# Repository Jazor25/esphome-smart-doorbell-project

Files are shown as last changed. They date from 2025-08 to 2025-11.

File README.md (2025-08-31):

# ESPHome Smart Doorbell Project

This smart doorbell project transforms a traditional doorbell into an intelligent system using ESPHome and Home Assistant integration. The system detects doorbell button presses and activates a relay-controlled chime while providing remote control capabilities. 

Doorbell detections can be used for home assistant automations such as taking a photo with your existing security camera on-press and send it with a notification to your mobile devices. You can also deactivate the gong/chime at times where you need silence.

Some ideas come from the excellent work of [Marcel Zuidwijk](https://www.zuidwijk.com/esphome-based-doorbell/).

### Visuals
More images are in the img folder.

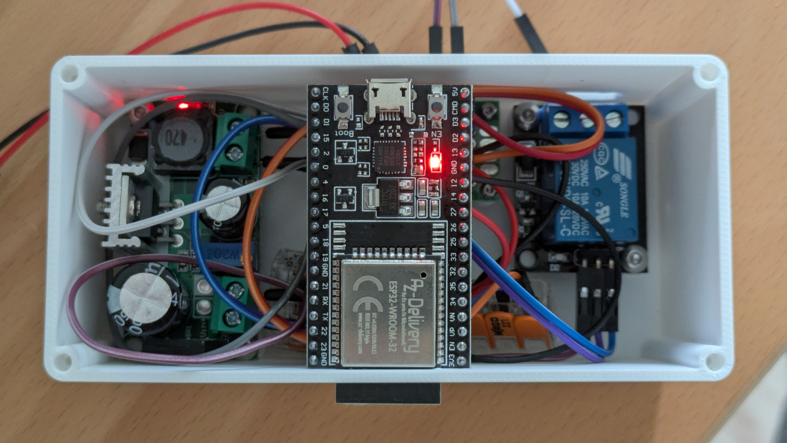
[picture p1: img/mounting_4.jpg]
Mounting

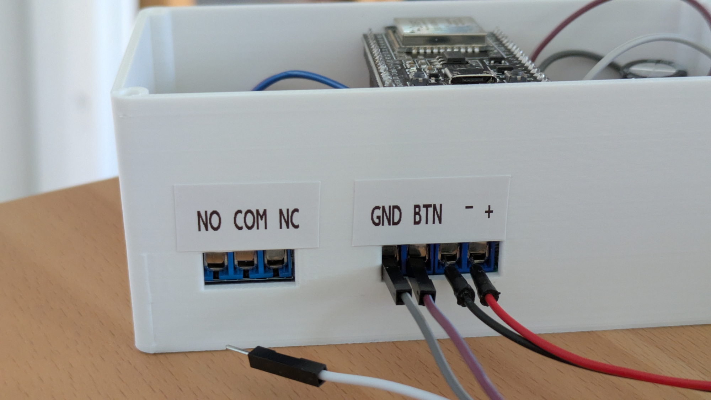
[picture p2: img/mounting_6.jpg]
Connections

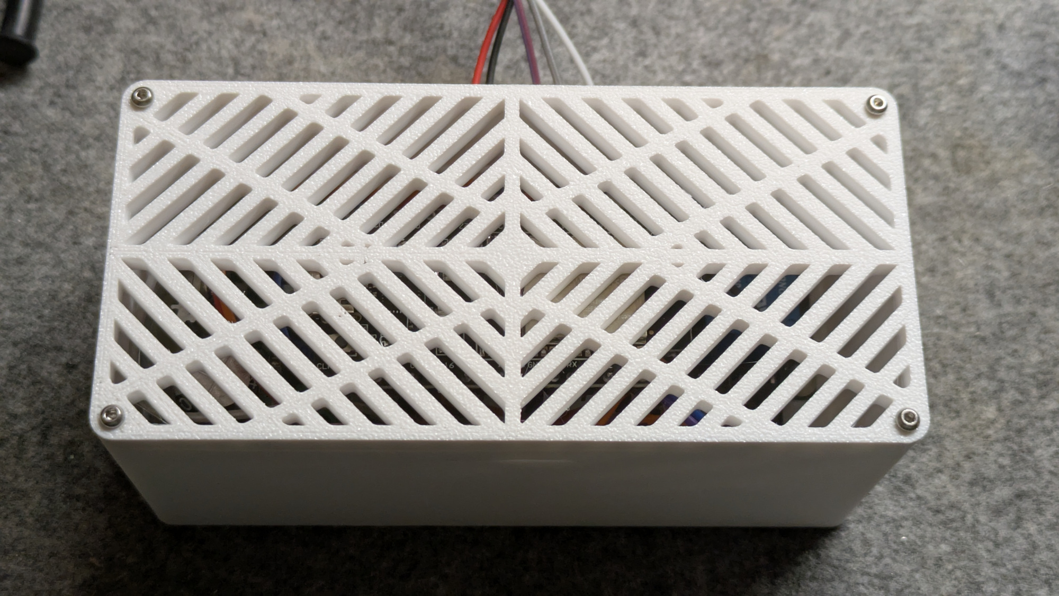
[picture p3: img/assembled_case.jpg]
Assembled

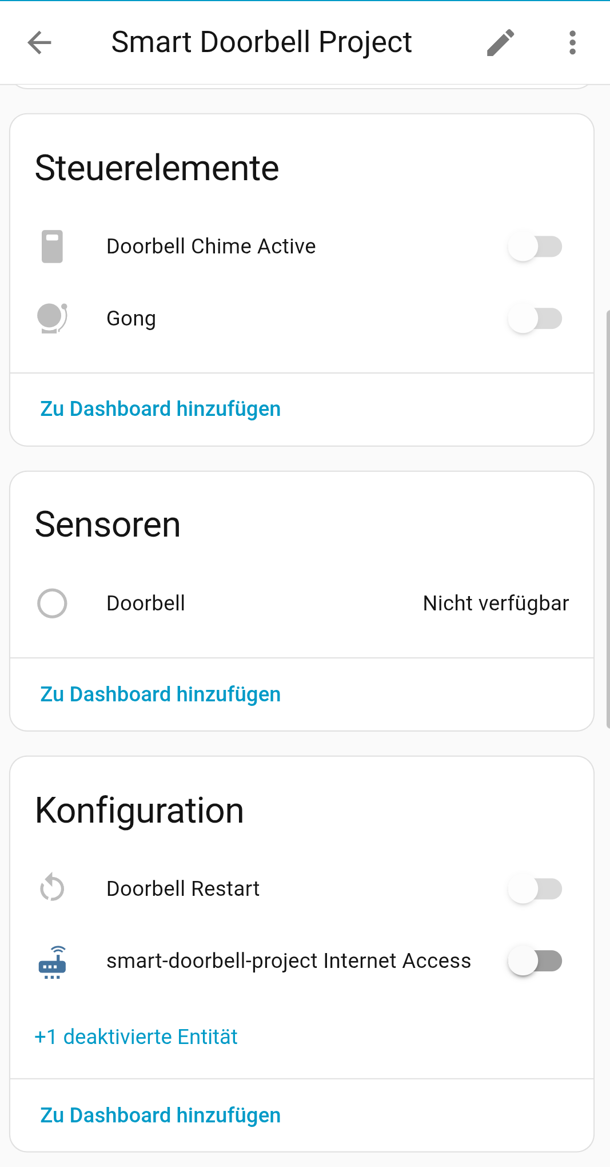
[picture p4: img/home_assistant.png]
In Home Assistant

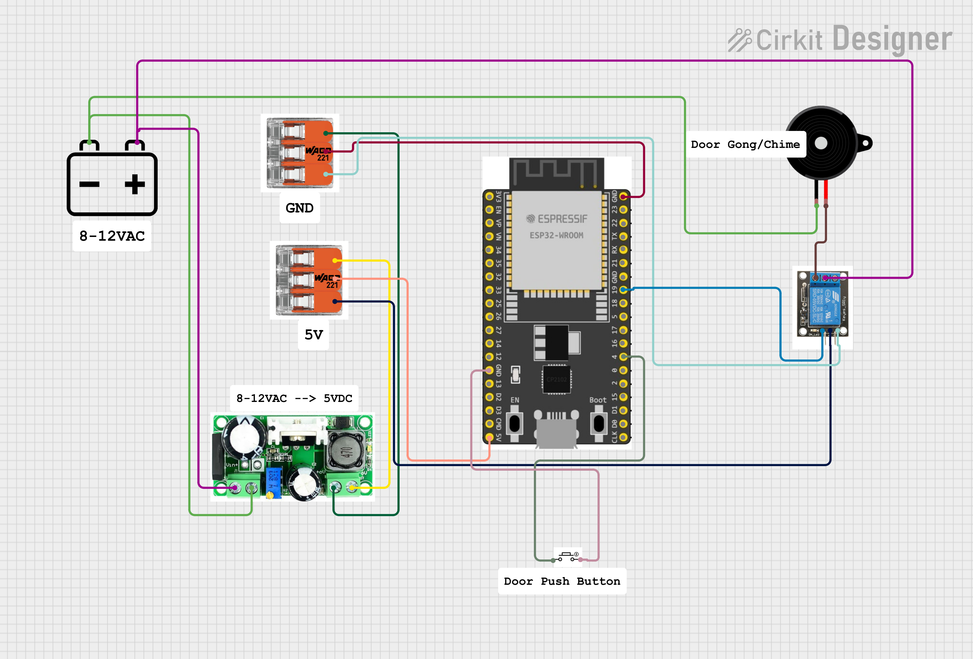
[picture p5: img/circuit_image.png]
Circuit Design


### Features
- Detects button presses via GPIO input with debouncing to avoid false positives
- Enable/disable chime remotely via Home Assistant in case you need silence
- Connects to home network with fallback hotspot
- Home Assistant Integration 
- Uptime and WiFi signal strength monitoring
- Restart device remotely
- Manual gong trigger via Home Assistant to annoy your housemate ;)

## Required Hardware
* ESP32 Development Board (Used: ESP32 V4 with CP2102, AZDelivery). As most dev boards, this one can handle 5VDC.
* 1× AC/DC LM2596hv Step-Down Voltage Regulator (to convert AC to DC and decrease voltage to 5V to power ESP32 and Relais module). AC to DC is important in case you want to connect this project to your existing doorbell transformer which typically runs on 8-12VAC 
* 1× SRD-05VDC-5L-C Relais Module because the typical Gong needs more amp that an esp32 can deliver. This Relais can also handle AC which would be tricky using Mosfets.
* To be powered over doorbell transformer (usually 8-12VAC) or external power source. Alternatively a separate transformer can be used. A separate transformer that delivers 5VDC would make the above mentioned step-down regulator dispensable.
* wiring cables
* Optional: WAGO connectors, terminal clamps and perfboard for easier wiring (see images)

## Wiring & Setup

## Installation & Configuration
See [docs/installation_configuration.md](docs/installation_configuration.md)  

### GPIO Pin Assignments
- **GPIO4**: Doorbell button input (with internal pullup)
- **GPIO19**: Relay control output (to trigger the gong)

### Power Supply Setup
1. **Input**: 8-12VAC from doorbell transformer
2. **Conversion**: LM2596hv Step-Down Voltage Regulator converts AC to 5VDC
3. **Distribution**: 5VDC powers both ESP32 and relay module

### Connection Diagram
```
Doorbell Transformer (8-12VAC)
    ↓
LM2596hv Voltage Regulator
    ↓ (5VDC)
    ├── ESP32 Board (VCC + GND)
    └── SRD-05VDC-5L-C Relay Module (VCC + GND)

Doorbell Button → GPIO4 (ESP32)
ESP32 GPIO19 → Relay Control Input
Relay Output → gong
```

### Assembly Notes
- Ensure proper AC/DC isolation when working with doorbell transformer
- Test all connections before final installation
- Voltage Regulation: The buck converter must be precisely adjusted to 5V to prevent damage to the ESP32 and connected modules. Connect 8-12VAC to the input pins, attach a multimeter (set to voltage mode) to the output pins, and carefully adjust the potentiometer with a screwdriver until the multimeter reads exactly 5VDC. This may be readjusted when you switch to different input voltage.

### 3D Print Case Hardware
- 4x Ruthex M3 Threaded Inserts
- 4x M3 Screws
- 6x Ruthex M2 Threaded Inserts
- 6x M2 Screws

### Key Configuration Options

**Doorbell Input**:
- Pin: GPIO4 with internal pullup
- Debouncing: 25ms delays to prevent false triggers

**Relay Output**:
- Pin: GPIO19
- Activation time: 1 second pulse to trigger the gong
- Control: global chime (gong) enable/disable setting

**Network**:
- Primary: Your WiFi network
- Fallback: Creates "Smart-Doorbell-Project" hotspot
- Captive portal for easy configuration
- Basic functionality runs without any network connection, to ensure that the doorbell works proberly in case of network outage

### Customization Options
- Change GPIO pins by modifying pin numbers in YAML
- Adjust chime duration by changing delay value
- Modify debounce timing for different button types
- Add additional sensors or switches as needed

### Operation Modes

**Enabled (Default)**:
- Doorbell button press → Relay activates → Chime sounds
- Green indicator in Home Assistant

**Disabled**:
- Doorbell button press → No relay activation → Silent
- Red indicator in Home Assistant
- Button press still logged for notifications

## Troubleshooting

### WiFi Connection Issues

**Device won't connect to WiFi**:
1. Verify `secrets.yaml` contains correct WiFi credentials
2. Check WiFi signal strength at installation location
3. Ensure WiFi network is 2.4GHz (ESP32 doesn't support 5GHz)
4. Look for fallback hotspot "Smart-Doorbell-Project"

**Fallback Hotspot Setup**:
1. Connect to "Smart-Doorbell-Project" network
2. Use password from `ap_wifi_password_sdb` in secrets
3. Navigate to captive portal page
4. Configure WiFi settings

### Hardware Issues

**Doorbell not responding**:
1. Check GPIO4 wiring and connections
2. Verify button is normally open (closes when pressed)
3. Test button with multimeter (should show continuity when pressed)
4. Check ESPHome logs for button state changes

**Relay not activating**:
1. Verify GPIO19 connection to relay module
2. Check 5V power supply to relay module
3. Test relay manually with multimeter
4. Ensure "Doorbell Chime Active" switch is ON in Home Assistant

## License
This project is published under [CC BY-NC-SA 4.0](https://creativecommons.org/licenses/by-nc-sa/4.0/).

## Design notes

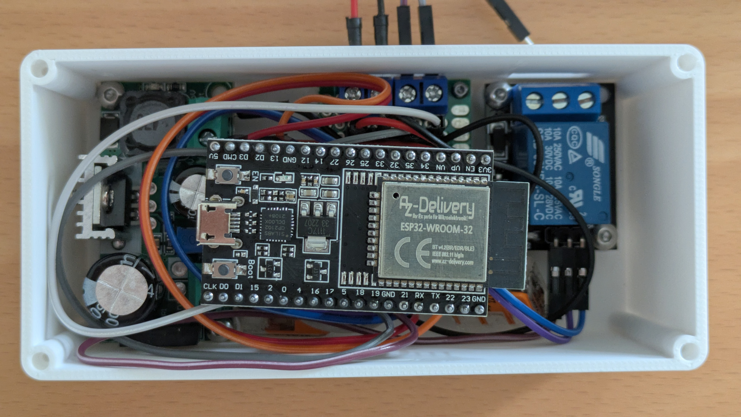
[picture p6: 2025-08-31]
img/mounting_7.jpg

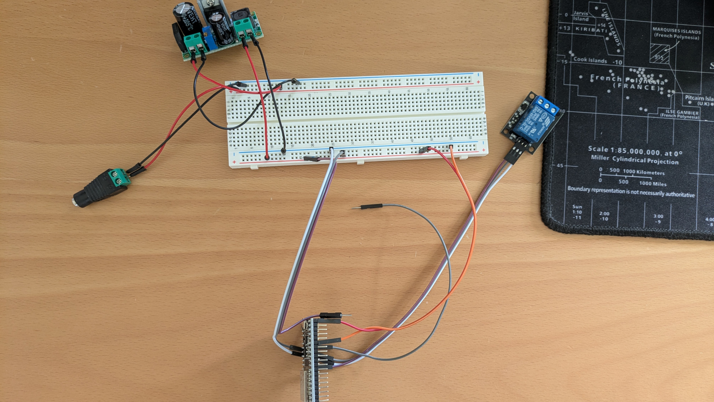
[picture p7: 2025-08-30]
img/prototype.jpg

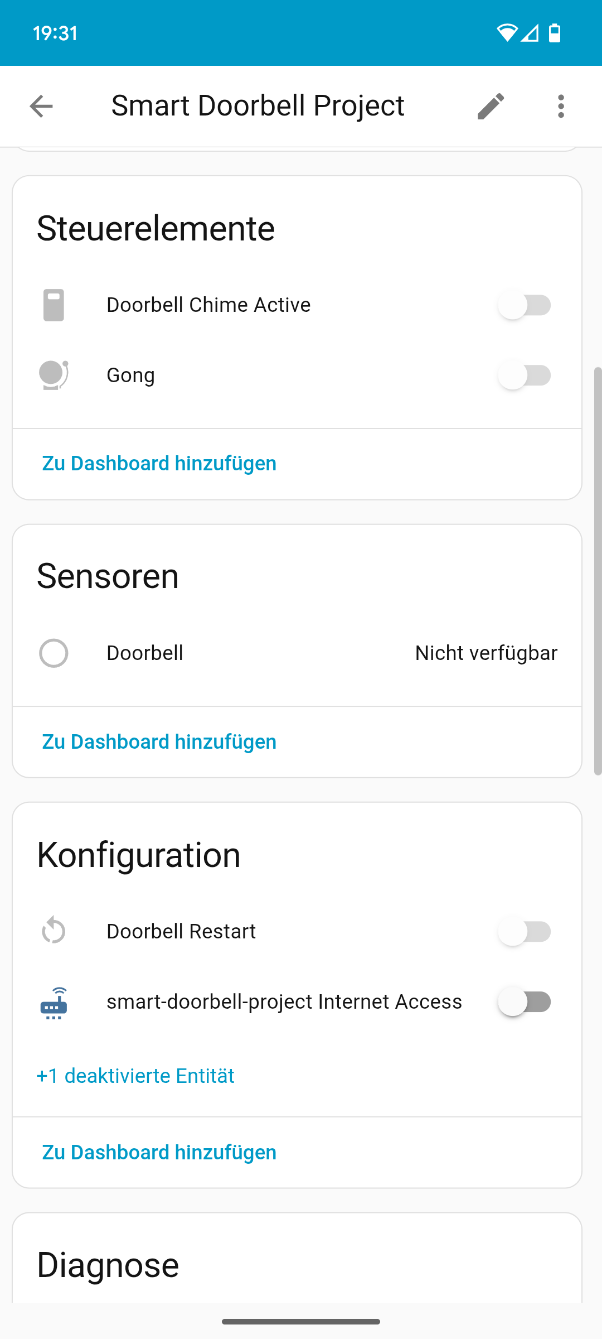
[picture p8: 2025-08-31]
img/Screenshot_20250831-193113.png

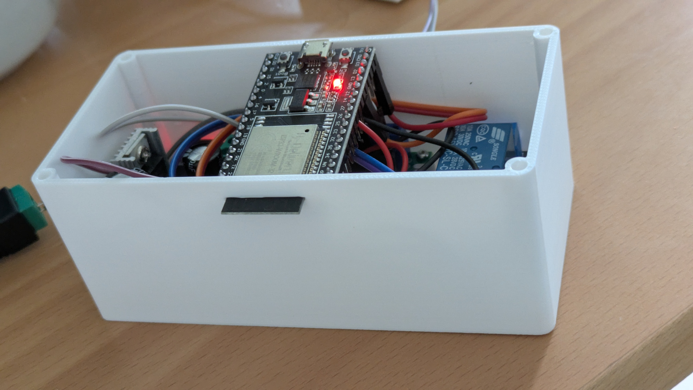
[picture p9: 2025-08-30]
img/mounting_5.jpg

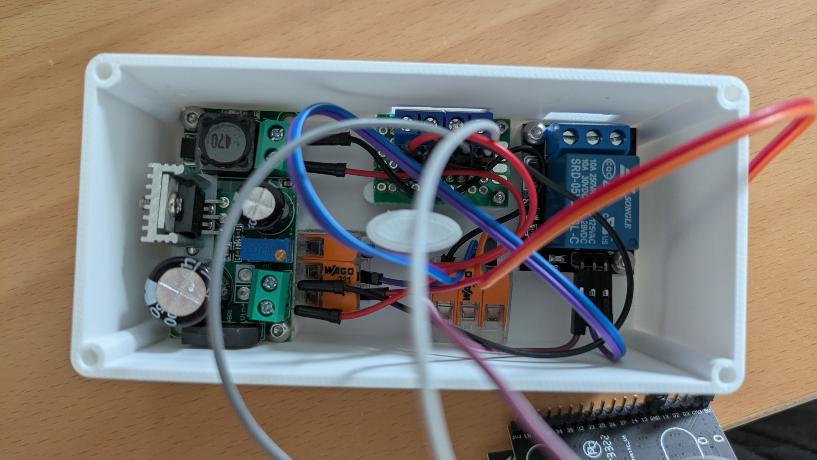
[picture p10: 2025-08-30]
img/mounting_3.jpg

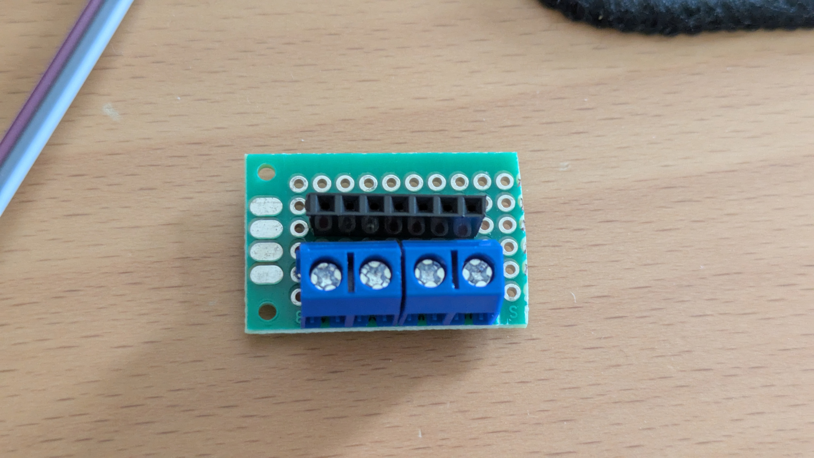
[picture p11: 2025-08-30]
img/terminal_clamps.jpg

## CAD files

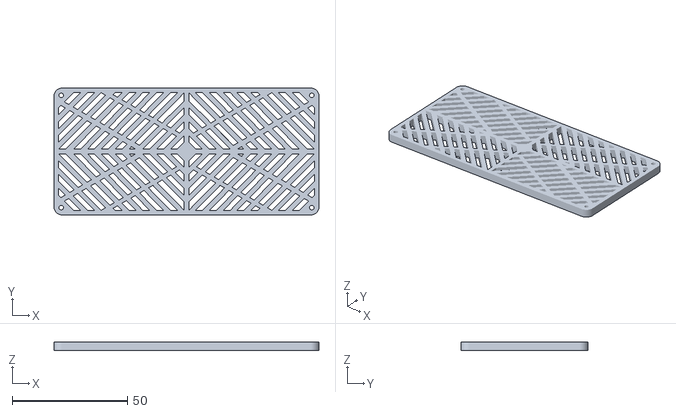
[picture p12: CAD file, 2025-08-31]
3d-print-files/Case_Top.stl
115.0 x 55.0 x 4.50

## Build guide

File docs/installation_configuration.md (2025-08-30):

# Adding ESPHome Smart Doorbell Project to Home Assistant

## Method 1: ESPHome Add-on (Recommended)

### Prerequisites
- Home Assistant with Supervisor (Home Assistant OS or Supervised)
- ESPHome Add-on installed

### Step-by-Step Instructions

#### 1. Install ESPHome Add-on
1. Go to **Settings** → **Add-ons** → **Add-on Store**
2. Search for "ESPHome" 
3. Click **Install** on the official ESPHome add-on
4. Start the add-on and enable **Start on boot**

#### 2. Add Your Device
1. Open ESPHome add-on web UI
2. Click **+ NEW DEVICE**
3. Choose **Continue** 
4. Enter device details:
   - **Name**: `smart-doorbell-project`
   - **Device Type**: Choose ESP32
5. Skip the wireless credentials (we'll use existing config)

#### 3. Upload Your Configuration
1. In ESPHome dashboard, click **EDIT** on your new device
2. Replace the generated content with your `smart-doorbell-project.yaml` content
3. Create a `secrets.yaml` file with:
   ```yaml
   wifi_ssid: "Your_WiFi_Name"
   wifi_password: "Your_WiFi_Password"
   api_encryption_key_sdb: "your-32-character-base64-encryption-key"
   ota_password_sdb: "your-secure-ota-password"
   ap_wifi_password_sdb: "your-hotspot-password"
   ```
4. Click **SAVE**

#### 4. Compile and Flash
1. Click **INSTALL** 
2. Choose **Wirelessly** (if device is already flashed) or **Plug into this computer**
3. Wait for compilation and upload

#### 5. Auto-Discovery in Home Assistant
- Once online, the device should appear in **Settings** → **Devices & Services**
- Look for "ESPHome" integration with your device
- Click **CONFIGURE** if prompted

## Method 2: Standalone ESPHome Installation

### If you're running ESPHome separately (not as HA add-on):

#### 1. Ensure API Configuration
Your configuration already has the API enabled:
```yaml
api:
  encryption:
    key: !secret api_encryption_key_sdb
```

#### 2. Manual Integration
1. Go to **Settings** → **Devices & Services**
2. Click **+ ADD INTEGRATION**
3. Search for "ESPHome"
4. Enter your ESP32's IP address
5. Enter the encryption key from your ESPHome config

## Method 3: MQTT Integration (Alternative)

### If you prefer MQTT, add this to your ESPHome config:

```yaml
mqtt:
  broker: your_mqtt_broker_ip
  username: !secret mqtt_username
  password: !secret mqtt_password
  discovery: true
  discovery_retain: false
  topic_prefix: esphome/smart_doorbell_project
```

## Device Configuration for Better HA Integration

### Add Device Information
Add this to your ESPHome configuration for better device identification:

```yaml
esphome:
  name: smart-doorbell-project
  friendly_name: Smart Doorbell Project
  comment: "Smart doorbell with chime control system"
  project:
    name: "custom.smart_doorbell"
    version: "1.0"

# Device information for Home Assistant
device_info:
  manufacturer: "Custom Build"
  model: "ESP32 Smart Doorbell"
  sw_version: "1.0"
```

## Expected Home Assistant Entities

After successful integration, you'll see these entities:

### 🔔 **Doorbell Controls**
- `switch.doorbell_chime_active` - Enable/disable the chime
- `switch.doorbell_restart` - Remotely restart the device

### � **Sensors**
- `binary_sensor.doorbell` - Shows when doorbell button is pressed
- `sensor.doorbell_uptime` - Device uptime
- `sensor.doorbell_wifi_signal` - WiFi signal strength

### 🏠 **Device Status**
- `binary_sensor.smart_doorbell_project_status` (online/offline)

## Creating a Dashboard Card

### Example Lovelace Card Configuration:

```yaml
type: entities
title: Smart Doorbell System
entities:
  - entity: binary_sensor.doorbell
    name: Doorbell Button
  - entity: switch.doorbell_chime_active
    name: Chime Active
  - type: divider
  - entity: sensor.doorbell_uptime
    name: System Uptime
  - entity: sensor.doorbell_wifi_signal
    name: WiFi Signal
  - type: divider
  - entity: switch.doorbell_restart
    name: Restart Device
```

## Automation Example

### Create automations in Home Assistant:

```yaml
# Example: Notification when doorbell is pressed
automation:
  - alias: "Doorbell Notification"
    trigger:
      - platform: state
        entity_id: binary_sensor.doorbell
        to: 'on'
    action:
      - service: notify.mobile_app_your_phone
        data:
          title: "Doorbell"
          message: "Someone is at the door!"

# Example: Disable chime at night
  - alias: "Disable doorbell chime at night"
    trigger:
      - platform: time
        at: "22:00:00"
    action:
      - service: switch.turn_off
        target:
          entity_id: switch.doorbell_chime_active

# Example: Enable chime in morning
  - alias: "Enable doorbell chime in morning"
    trigger:
      - platform: time
        at: "07:00:00"
    action:
      - service: switch.turn_on
        target:
          entity_id: switch.doorbell_chime_active
```

## Troubleshooting

### Device Not Appearing
1. **Check Network**: Ensure ESP32 and HA are on same network
2. **Verify API**: Confirm API encryption key matches
3. **Check Logs**: Look in HA logs for connection errors
4. **Manual Add**: Try adding via IP address manually

### Connection Issues
1. **Firewall**: Ensure port 6053 is open for ESPHome API
2. **WiFi Signal**: Check `sensor.doorbell_wifi_signal` strength
3. **Restart**: Reboot both ESP32 and Home Assistant

### Entity Names
- Entity names will be prefixed with your device name
- Use **Settings** → **Devices & Services** → **ESPHome** → your device to customize entity names

## Advanced Features

### Group Configuration
Create groups for easier management:

```yaml
# In configuration.yaml
group:
  doorbell_system:
    name: "Smart Doorbell System"
    entities:
      - switch.doorbell_chime_active
      - binary_sensor.doorbell
      - sensor.doorbell_uptime
      - sensor.doorbell_wifi_signal
```

### Template Sensors
Create calculated sensors:

```yaml
# Doorbell activity counter
template:
  - sensor:
      - name: "Daily Doorbell Presses"
        state: >
          {{ states.binary_sensor.doorbell.attributes.get('count', 0) }}
        unit_of_measurement: "presses"
```

Once you follow these steps, your ESPHome smart doorbell system will be fully integrated into Home Assistant with all entities available for monitoring, control, and automation!

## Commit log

2025-08-30 documentation + secrets sample
2025-08-31 added 3D print files
    [Case_Top.stl]
2025-11-12 fixed circuit image
